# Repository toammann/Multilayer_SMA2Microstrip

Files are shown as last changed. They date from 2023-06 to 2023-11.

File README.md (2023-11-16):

# An Open-Source Multilayer SMA Coaxial to Microstrip Transition

Recently I came across [openEMS](https://www.openems.de/), a free and open electromagnetic field solver using the FDTD method.

The project has been around a few years, and it is quite impressive how far it has developed (05/2023). I was wondering if it is possible to solve a complex RF simulation task using open-source software only.

A license of a typical commercial RF simulation environment (CST, ADS, AWR...) can cost $1000/month easily. This price is out of range for hobbyists and small companies that do not use these software products on a daily basis.

I chose the task below as a representative test case:
> "Design a high performance SMA (SubMiniature version A) low cost Coaxial to Microstrip transition up to 20GHz on a FR4 multilayer stackup fabricated by an affordable PCB prototyping service."

Simulation tasks of this kind must be solved in the RF industry frequently because the transition needs to be designed for each specific layer stack with its own characteristic substrate materials, thicknesses and metal layers.

A list of open-source software used in this project:
- [OpenEMS](https://www.openems.de/)
- [FreeCAD](https://www.freecad.org/)
- [GNU Octave](https://octave.org/)
- [KiCAD](https://www.kicad.org/)
- [ParaView](https://www.paraview.org/)
- [QUCS](https://qucs.sourceforge.net/)
- [VS Code](https://code.visualstudio.com/)
- [Inkscape](https://inkscape.org/)
- [IEEE P370 Standard](https://opensource.ieee.org/elec-char/ieee-370)

## 1. Table of Contents

- [1. Table of Contents](#1-table-of-contents)
- [2. Rosenberger 32K242-40ML5 SMA Connector](#2-rosenberger-32k242-40ml5-sma-connector)
- [3. The Connector Model](#3-the-connector-model)
- [4. PCB Design Considerations and Manufacturing](#4-pcb-design-considerations-and-manufacturing)
- [5. Simulation Workflow](#5-simulation-workflow)
- [6. Simulation Results](#6-simulation-results)
- [7. Measurement Results](#7-measurement-results)
- [8. Conclusion](#8-conclusion)
- [9. KiCAD Howto](#9-kicad-howto)

## 2. Rosenberger 32K242-40ML5 SMA Connector
I have chosen a typical right-angle jack SMA connector. This connector type requires a cutout in the PCB edge, which is an additional design and manufacturing effort.

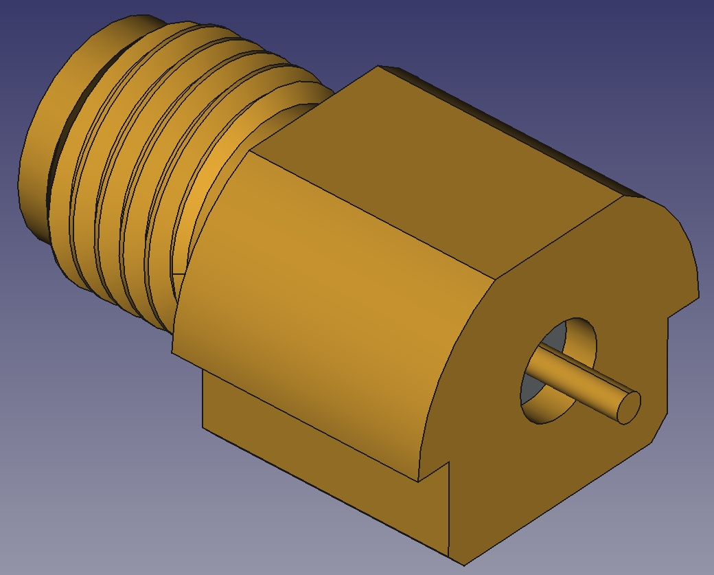
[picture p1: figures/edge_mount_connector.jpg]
fig_conn_wuerth

<p align = "center">Figure 1: A typical edge mount SMA connector to be mounted in a cutout.</p>

However, I like these connectors because the solder mount is very strong due to the large mounting area which results in very good mechanical durability. The parasitic inductance in the return current is also low because the solder joint is right at the circular edge of the coaxial outer conductor.

 Connectors of this kind are available from multiple manufacturers (Molex, Würth, Rosenberger...). I went with the Rosenberger one due to its availability where I live. Specifically, the 32K242-40ML5 made the run. It was about 6€ at rs-online.com. Figure 1 shows an exemplary CAD model of the Würth 60312202114307 (Rosenberger does not provide CAD a model for their part).

## 3. The Connector Model
Typically, the first step in designing a coaxial to microstrip transition is to request a simulation or mechanical model from the connector vendor. 

Today, most vendors provide detailed models for commercial simulators. However, in most cases an NDA (Non-Disclosure Agreement) is required. Sometimes the internals of the connector are even encrypted and therefore not visible to the user (e.g. SV Microwave).

I had no hope that Rosenberger would send a model to me - a private person without an NDA. I tried it nevertheless - with no success. They did not even bother to respond to my email.

So, in order to proceed the connector was cut in half with a rotary tool. The goal was to create a "poor man´s microsection view". I was quite surprised how well this tuned out. The result is good enough to take some measurements.

Ready to create a 3D model in FreeCAD!

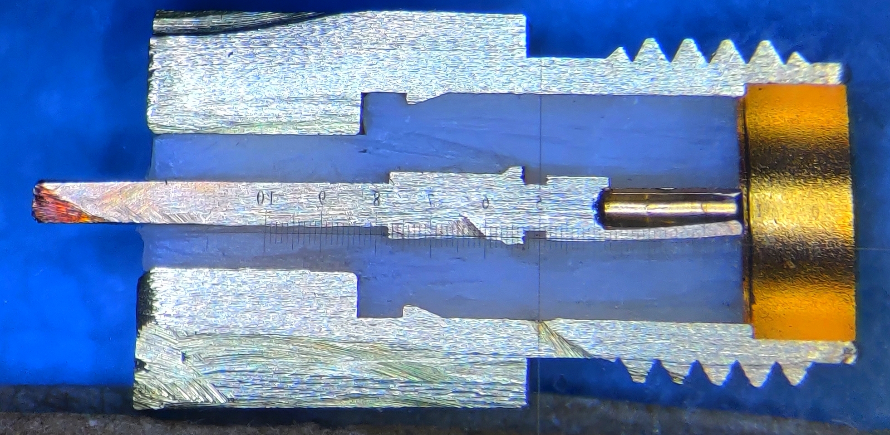
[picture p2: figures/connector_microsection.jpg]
fig_microsection

<p align = "center">Figure 2: Microsection view of the Rosenberger 32K242-40ML5</p>

To estimate the substrate permittivity, we can use the measured dimensions and the standard equation for the impedance of a coaxial waveguide. We know that the impedance inside of the connector must match $Z_0$=50Ohm at inner conductor clamping area on the right side of Figure 2. 

$$
    Z_0 = \frac{1}{2\pi}\sqrt{\frac{\mu_0\mu_r}{\epsilon_0\epsilon_r}}\ln\left(\frac{D}{d}\right)
$$

The relative permittivity of the connector substrate is found to be around $\epsilon_r$=2.08 for measured diameter values of D=4mm (outer), d=1.2mm (inner) and $\mu_r$=1,  $Z_0$=50Ohm. This is a typical value for a Teflon material.

## 4. PCB Design Considerations and Manufacturing
For a project of this kind choosing the right PCB (Printed Circuit Board) stackup and technology is actually more important than the choice of the SMA connector.

To prevent radiation effects at the interconnect, to minimize GND return current inductance and also for mechanical durability reasons it is usually beneficial to have an edge metallization in the area around the connector. However, this technology typically involves an additional PCB fabrication step which increases the cost significantly (which is especially true for common PCB prototyping platforms). Because this is a hobby project, I wanted it to be as cheap as possible.

In the past I have worked with a German PCB prototyping service [AISLER](https://aisler.net/?lang=en). I was quite satisfied with the quality of the delivered boards. Starting from 12/2022 AISLER has released a new FR4 6-layer PCB stackup that should work well for RF projects for various reasons. One very nice feature of AISLER is that "Castellated Holes" are free.

I had the idea to abuse this castellated hole feature to create a short piece of edge metallization. Placing the castellated holes and slots and also planning the board outline carefully was tricky. I even had to contact the support team of AISLER. The provided support was excellent!

The fabricated result is amazing! The edge metallization looks very, and it comes for free :)

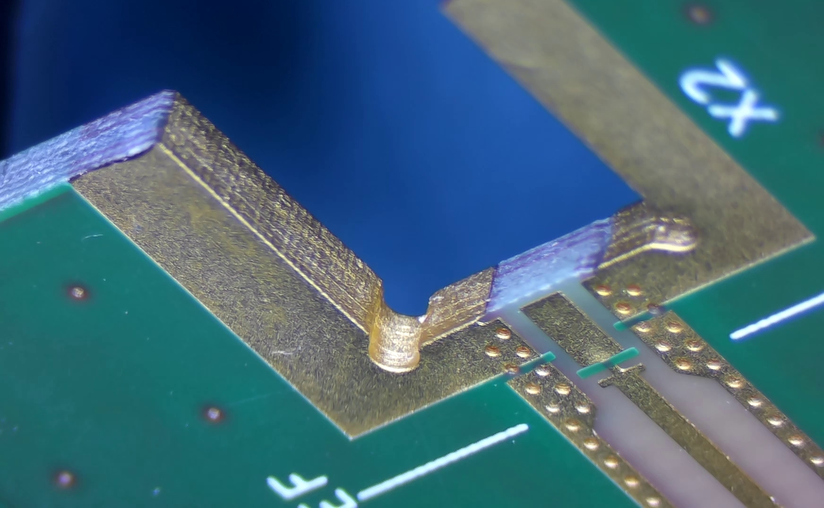
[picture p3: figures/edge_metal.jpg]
fig_edge_metal

<p align = "center">Figure 3: Edge-Metallization of the test board fabricated by AISLER using castellated slots.</p>

## 5. Simulation Workflow

There are two ways in openEMS to create the model required for the simulation. One can either use the octave/python interface to create the shapes that form the model directly in openEMS or to import *.stl mesh files.

I chose to create the entire model in FreeCAD. This has the benefit that all the import/export functions of FreeCAD can be used. One downside is that one might run into some [meshing issues](https://github.com/thliebig/openEMS-Project/discussions/43) if the mesh lines do not exactly hit the imported shapes (floating point accuracy).

The following figure shows the simulation workflow I came up with:

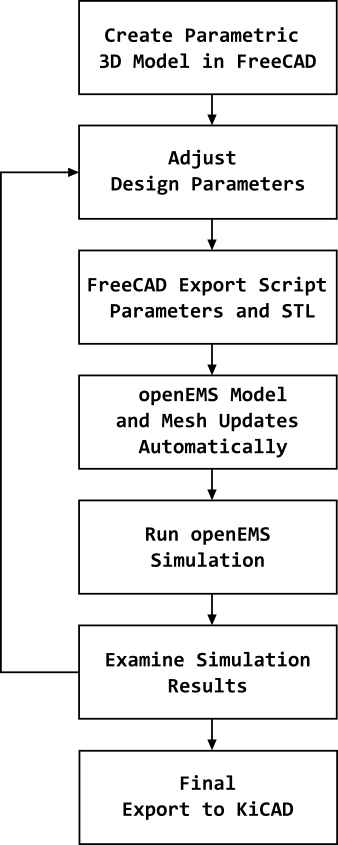
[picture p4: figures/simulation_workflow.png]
fig_simulation_workflow

<p align = "center">Figure 4: FreeCAD and openEMS Simulation Workflow</p>

This approach is quite powerful. The model dimensions are stored in one place only. So, when a dimension is changed in FreeCAD everything updates automatically. From the 3D model all the way to the mesh lines what enables quick and easy tuning of the model. In this way the workflow is almost similar to CST Microwave Studio, a commercial EM-Solver Suite.

Figure 5 shows the connector and PCB model in FreeCAD with a cut plane at y=0. The spreadsheet on the right side shows the parameter list where all dimensions of the model can be adjusted. The PCB core and prepreg materials are hidden.

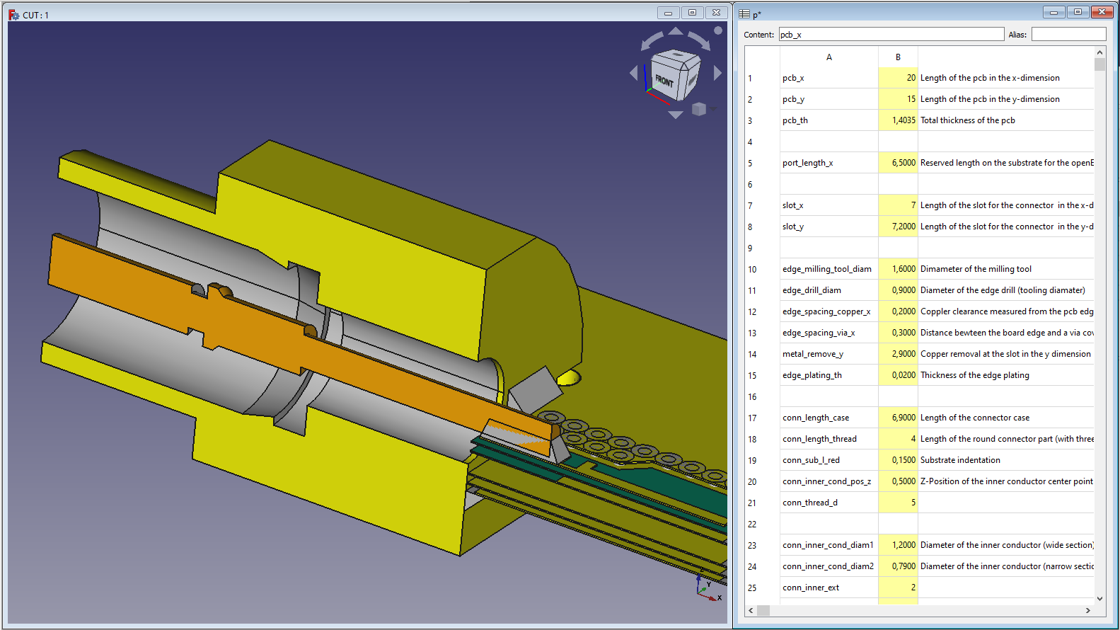
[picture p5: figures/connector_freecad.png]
fig_connector_freecad

<p align = "center">Figure 5: The Connector and PCB Model in FreeCAD</p>

Once the model parameters are settled in FreeCAD the user executes the Python FreeCAD export script which generates a set of *.stl files. These files are then imported by the octave openEMS script. Figure 6 shows the model and mesh result in AppCSXCAD the 3D Model editor/viewer of openEMS. 

Proper meshing techniques were applied in order to get a reasonably fast simulation and high accuracy results. One can clearly see how the mesh is denser in the area where the geometry details have a greater impact and less dense in less important areas.

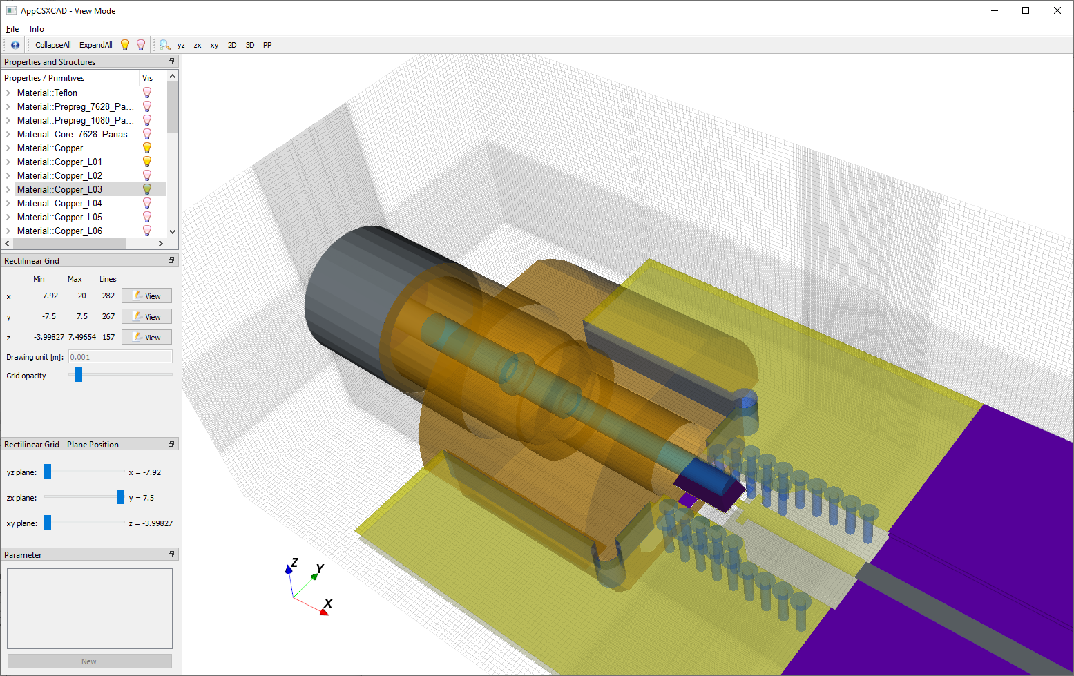
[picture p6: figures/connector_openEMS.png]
fig_connector_openems

<p align = "center">Figure 6: The Connector and PCB Model in AppCSXCAD (openEMS)</p>

The final output of the project - which is hopefully of use for the community - is a multilayer KiCAD footprint for the connector. Officially the KiCAD footprint editor does not support shapes on the internal metal layers. However, the footprint file can be modified with a text editor. Here shapes can be placed on the internal layers what works just fine. 

In order to use the KiCAD connector Footprint simply assign it to a symbol in the schematic and place "Copper Zones" (see example board) on the internal layers of your application board. Make sure to follow the  [bridges and frames](https://community.aisler.net/t/bridges-and-frames/49) design rules from AISLER. Everything else is handled in the KiCAD footprint.

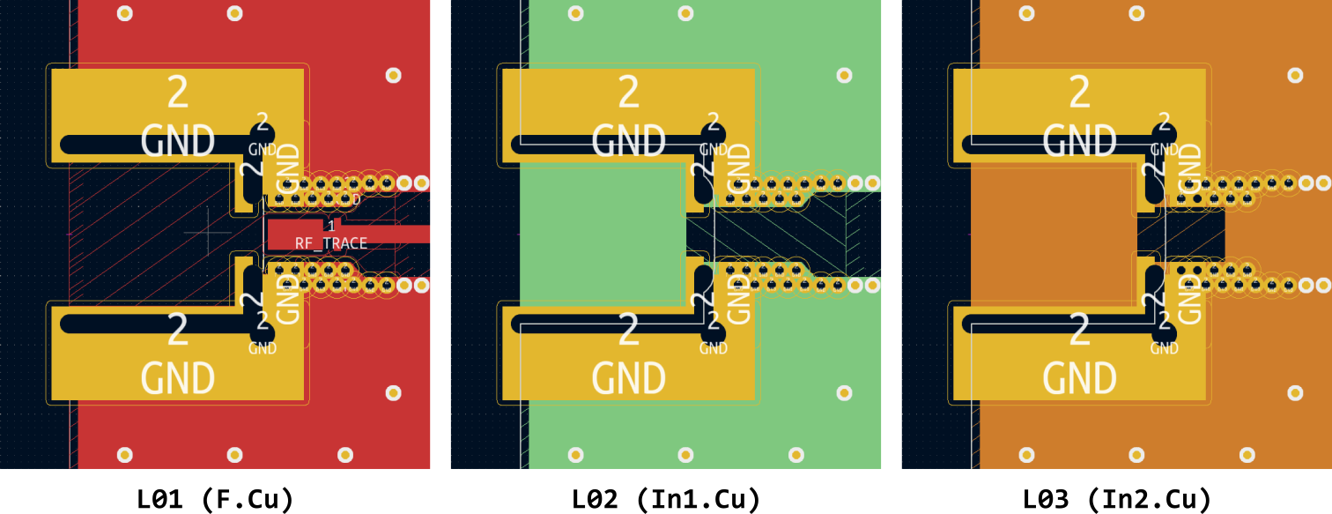
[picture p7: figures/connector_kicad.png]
fig_connector_kicad

<p align = "center">Figure 7: Multi-layer Connector Footprint in KiCAD.</p>

Finally, to test and measure the connector transition a 6-layer back-to-back test board was created in KiCAD. A total of three boards were manufactured by AISLER for around 20€. 

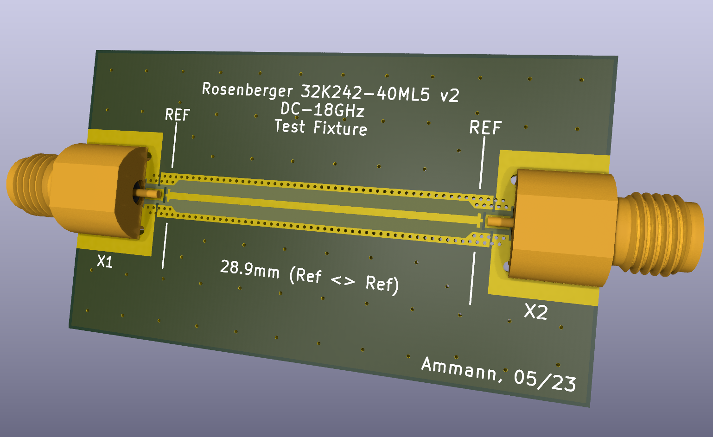
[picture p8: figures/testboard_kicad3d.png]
fig_tesetboard_kicad

<p align = "center">Figure 8: Test Fixture of the Rosenberger 32K242-40ML5 SMA Connector on  the AISLER 6LayerHD Stackup in KiCAD.</p>

After the fabrication of the PCB the SMA connectors were hand soldered on the test board as shown in Figure 9. 

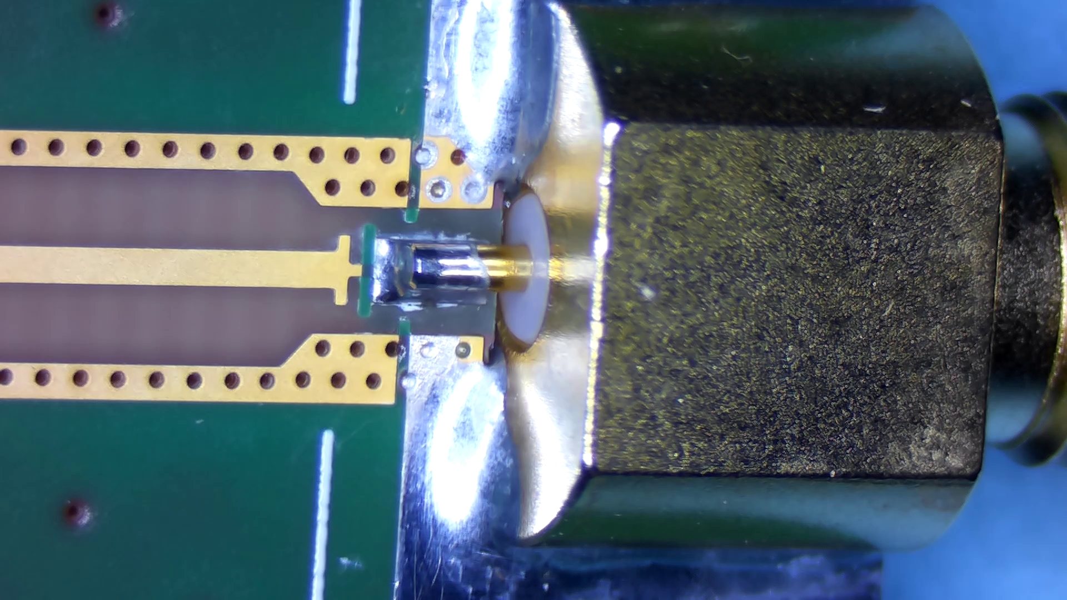
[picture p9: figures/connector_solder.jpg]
fig_connector_solder

<p align = "center">Figure 9: Rosenberger Connector Solder joint.</p>

## 6. Simulation Results

OpenEMS writes field data in a format suitable for ParaView. ParaView is an open software to visualize vector fields. Figure 9 shows an E-Field plot at the xz (y=0) plane (20GHz). One can clearly spot the transitions from the coaxial mode (vertical field vectors) to the microstrip mode. Also, the removal of the GND plane right under the connector Pad is noticeable. 

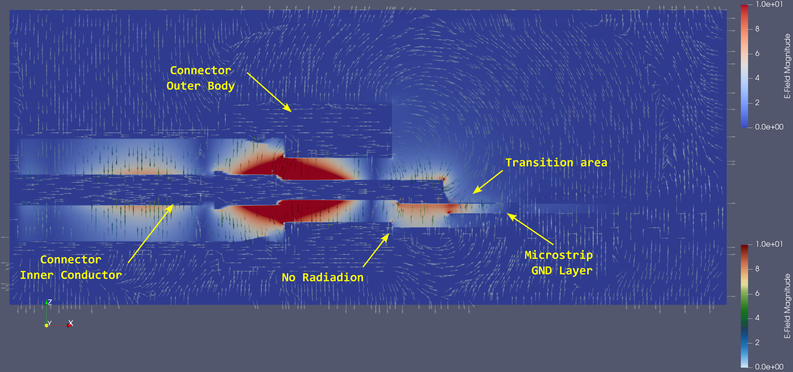
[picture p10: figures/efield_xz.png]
fig_efield

<p align = "center">Figure 10: Test Fixture of the Rosenberger 32K242-40ML5 SMA Connector on  the AISLER 6LayerHD Stackup.</p>

Above the right end of the inner conductor there is some small radiation visible. The field lines bend from the solder joint up to the top of the connector outer body. This undesired effect is given by the connectors construction and cannot be avoided.

At the edge where the connector and the PCB meet the internal copper layers of the PCB and the connector outer body form a parasitic parallel plate waveguide along the z dimension. It is important to avoid the excitation of this waveguide to prevent excessive leakage at higher frequencies. The field results clearly show that there is no radiation at the connector to PCB interface.

Finally let's examine the Scattering Parameters of the simulation. Figure 11 shows the simulation results calculated by openEMS. The reference plane for all S-Parameter results is located at the right edge of the capacitive compensation structure as shown in Figure 8. The exact location can be verified in the KiCAD PCB file. This edge is the transition where the connector footprint ends and the 50Ohm microstrip line starts. 

Port 1 is the coaxial one, Port 2 the microstrip port. A return loss greater than 23dB was achieved from DC to 20GHz.

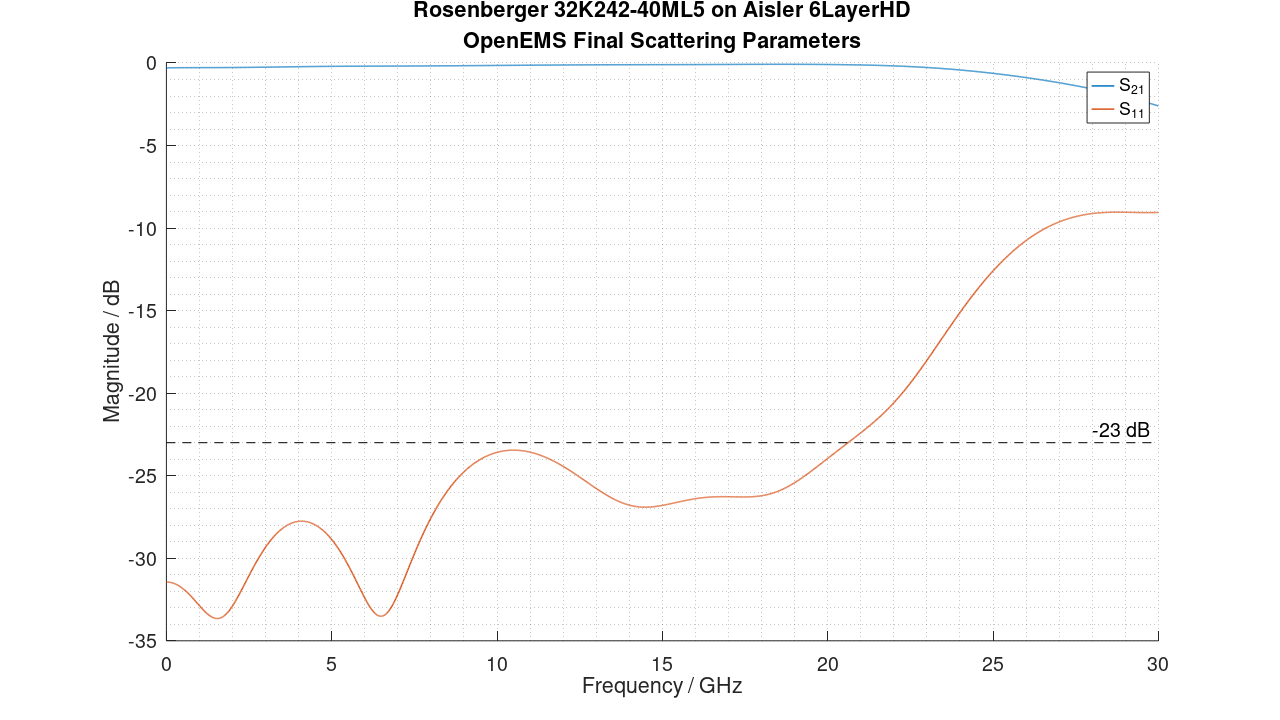
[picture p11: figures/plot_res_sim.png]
fig_plot_res_sim

<p align = "center">Figure 11: OpenEMS simulation result after optimization. Port 1 (coaxial), Port 2 (microstrip), Return Loss > 23dB.</p>

The smit chart plot in Figure 12 shows the in- and output trajectories on the complex reflection coefficient plane. They are nicely point symmetric to the origin. Overall, these results look promising. There is some margin for manufacturing tolerances left.

The openEMS simulation takes about 20 minutes to complete.

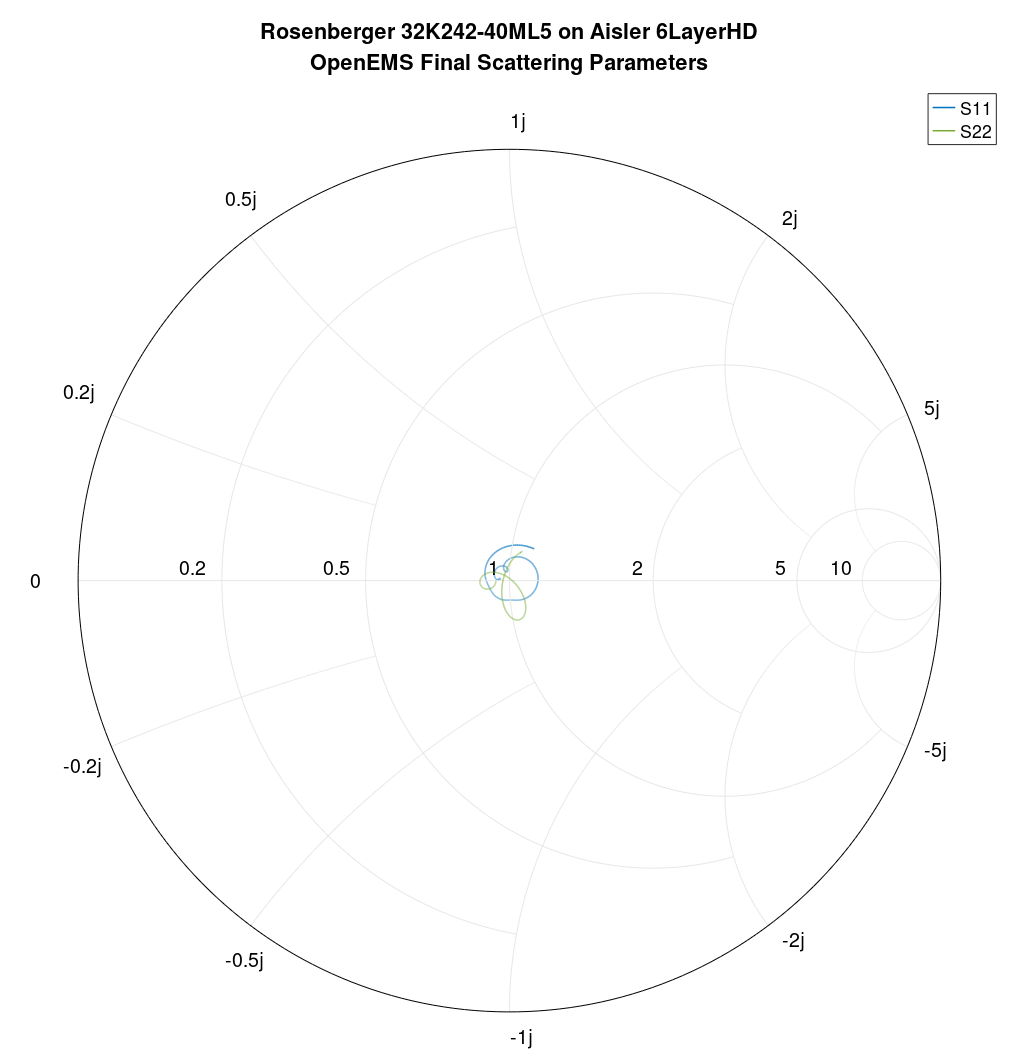
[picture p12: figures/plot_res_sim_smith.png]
fig_plot_res_sim_smith

<p align = "center">Figure 12: OpenEMS simulation result. In/ Output Matching from DC to 20GHz, Port 1 (coaxial), Port 2 (microstrip).</p>

## 7. Measurement Results

The fabricated test board from Figure 8 with two connectors back-to-back was measured with a high performance VNA (Vector Network Analyzer). The results are shown in Figure 13.

<p align = "center"><img src="./figures/plot_res_meas_testboard.png" alt="fig_plot_res_meas_testboard  width="800"></p>
<p align = "center">Figure 13: S-Parameter results, Test board Figure 8, two connectors back-to-back, reference plane at the SMA coax.</p>

Let´s take a closer look at this plot. The S21 curve is almost perfect. It is flat with no dips. However, one will notice that the magnitude return loss curves are not identical. So, the structure is not entirely symmetrical. This is due to manufacturing tolerances. Keep in mind that we are talking about a low-cost connector and PCB. The connectors are hand soldered, so some small displacements are expected.

In order to relate this result of Figure 13 to the simulated one in Figure 11 some approximate observations can be done. Approximately, we can think about the measured structure as two identical imperfectly matched two ports (the connector) with low insertion loss and an ideal transmission line in between. Because the insertion loss of the two ports is low, every miss match on either side will propagate directly through to the other side. The transmission line will further rotate the phase of the reflection coefficients with frequency. The 28.9mm transmission line is multiple wavelengths long at the highest frequency of interest (20GHz). So, it is safe to assume that all possible phase angles between the two imperfectly matched connectors will occur over frequency.

This phase related worst case impedance miss match $\Gamma_{max}$ may occur when two imperfectly matched ports with $|\Gamma_a|$ and $|\Gamma_b|$ are connected can be estimated from the following equation. It can be easily derived from the definition if the reflection coefficient:

$$
    |\Gamma_{max}| = \frac{|\Gamma_a| + |\Gamma_b|}{|\Gamma_a \Gamma_b| + 1}
$$

For this idealized analysis let´s assume identical connectors with $|\Gamma_a|=|\Gamma_b|=|\Gamma|$. From Figure 13 we take $|\Gamma_{max}|$=-15.67dB. Solving the above equation for $|\Gamma|$ gives us an estimation of the connector two-port return loss of:

$$
    |\Gamma| = \frac{1- \sqrt{1-|\Gamma_{max}|^2}}{|\Gamma_{max}|}= -21.63\mathrm{dB}
$$

So, we know simply by looking at Figure 13 closely that the achieved measured return loss of the connector is slightly worse than in the simulation.

To properly compare the simulation with the measurement results some advanced mathematical postprocessing must be applied to the data of Figure 13. There are two options: 

1. Perform a S-Parameter simulation using the touchstone files of the EM-simulation to model the back-to-back structure from Figure 8. In the simulator place the touchstone files back-to-back with a transmission line of the correct length in between. 
2. Cut the structure mathematically in half to separate the left from the right connector. De-embed the remaining transmission line in a second step.

Method 1. has the benefit of being easy to generate using any standard S-Parameter simulator such as Qucs. The downside of this method is that the single connector characteristics (left or right) are not extracted. However, the single connector characteristics are the one of interest when using the connector in an actual circuit. 

The approach in Method 2 extracts these single connector characteristics. This data can be compared directly to the simulation result which is desirable. However, the output data of this method is more difficult to generate.
The IEEE P370 Standard [(Electrical Characterization of Printed Circuit Board and Related Interconnects at Frequencies up to 50 GHz) ](https://ieeexplore.ieee.org/document/8078138) comes with an open source mathematical algorithm to achieve this goal. The source code can be found on the [IEEE GitLab](https://opensource.ieee.org/elec-char/ieee-370). Internally, it uses a time domain transformation approach.

Finally Figure 14 shows the prost processed measurement results from Figure 13 by applying Method 2 on the measured data.

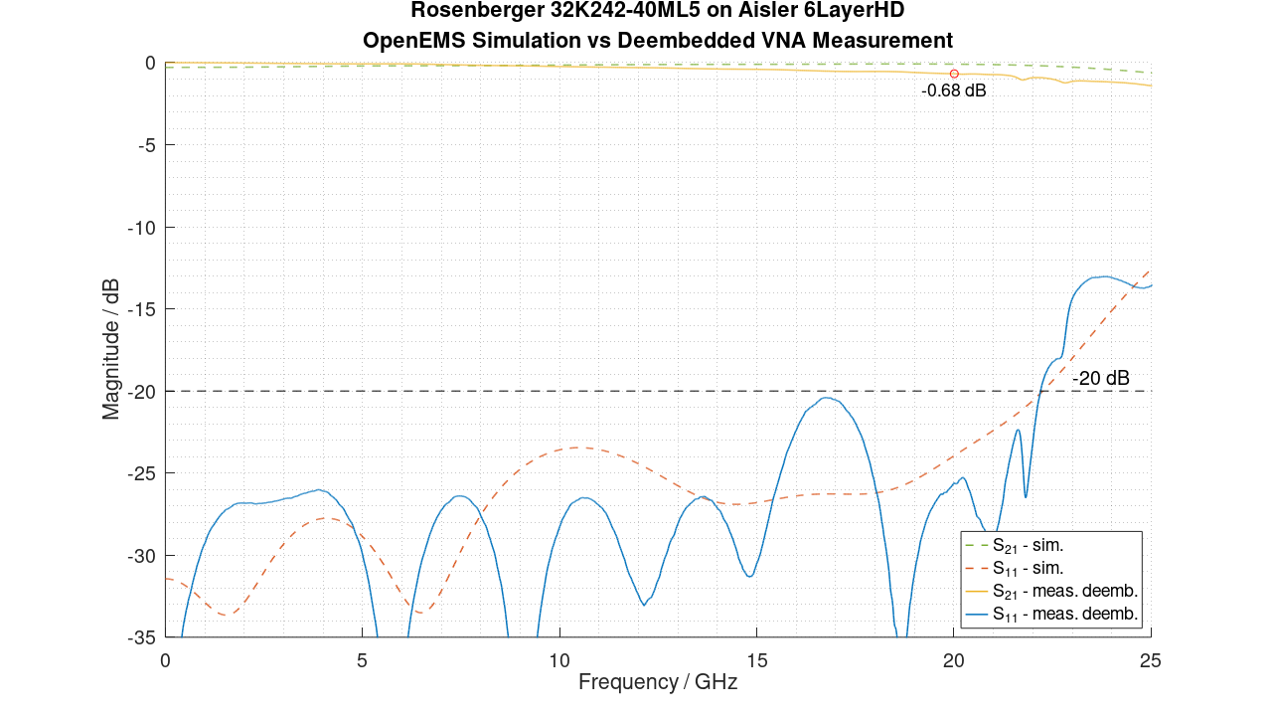
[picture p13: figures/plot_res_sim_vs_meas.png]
fig_plot_res_sim_vs_meas

<p align = "center">Figure 14: OpenEMS Simulated S-Parameters vs. VNA-Measurement (Post-Processed/De-Embedded via Method 2).</p>

We can see that the worst-case insertion loss around 17.5GHz is very close to our estimated value of -21.63dB which was calculated above. Overall, the agreement is impressive considering the large manufacturing tolerances of a PCB fabricated by a prototyping service and a hand soldered connector.

The connector itself has a very large return loss tolerance specification. From the datasheet:
> VSWR = 1.1 + 0.02 x 20GHz = 1.5 (RL = 14dB)

This is much worse than the measured result on its own! So, overall, the agreement is remarkable.

## 8. Conclusion

To test the openEMS FDTD-Solver a SMA coaxial to microstrip transition was designed and simulated. 

The Rosenberger 32K242-40ML5 connector has been integrated on a 6-layer test board with FR4 substrate fabricated by AISLER a German PCB prototyping service. Using castellated holes in a suitable configuration a PCB edge metallization has been realized with no additional cost. Finally, an easy-to-use KiCAD footprint was created. The footprint enables the user to design complex RF circuits up to 20GHz on the AISER 6LayerHD FR4 stackup.  

The transition is very low-cost and intended for hobbyist and prototyping use. A 20GHz SMA transition for under 20€ as a "one off prototype order" is to my knowledge unique. 

<div align="center">

| Item | Cost |
|:---|:---|
| 6-Layer PCB by AISLER (one piece)  | 20€/3 = 6.67€ |
| Rosenberger connector (two pieces) | 2*6€ = 12€ |
| Total Cost | 18.67€ |

 </div>

This case study shows that it is possible to design high performance RF hardware using open-source software only.

The agreement between simulated and measured results is very good especially considering the high manufacturing tolerances due to hand soldering and a low-cost PCB. OpenEMS does a remarkable job here! In my opinion this simulator gets way too little attention for its capabilities.

Unfortunately, openEMS lacks detailed training materials what makes the software hard to use for a beginner. This case study demonstrates how powerful this free software actually is. Hopefully, it will encourage other people to publish simulated and measured results. This will greatly improve the confidence in the simulator and hopefully attract more users. 

The more users the more information is available in the form of tutorials or forum discussions.

## 9. KiCAD Howto
Please find instructons how to use the KiCAD footprint [here](./KiCAD_Rosenberger_32K242-40ML5_Footprint/Rosenberger_32K242-40ML5_Footprint_HowTo.md).

 ### License Information

- Layouts, 3D models, footprints: Creative Commons Legal Code CC0 1.0 Universal
- Program code: BSD 2-Clause License

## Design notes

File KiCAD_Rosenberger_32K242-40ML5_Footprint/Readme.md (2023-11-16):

# How to Use the Rosenberger32K242-40ML5 KiCAD Footprint

## Version History
 - 15.11.2023 - Update milling contours to support the AISLER 1.8mm outline tool diameter update.  
 - 16.08.2023 - Updated RF structure
 - 05.05.2023 - Initial: Rosenberger_32K242-40ML5v1.kicad_mod

## Current Status
 - Unferified (changes were made to the design but there was no fabrication run)
## Requirements
- Tested with KiCAD 7.0
- Compatible with the  [AISLER 6LayerHD](https://community.aisler.net/t/6-layer-hd-pcb-stackup/1703)
 stakup only. NO other layer stack will work

## Installation Instructions

1. Save the footprint folder to a location of your choice
2. Add the "RF_Connectors.pretty" folder to your KiCAD footprint library (Footprint Editor -> Manage Footprint Libraries)
3. Make sure that the STEP file "Rosenberger_32K242-40ML5.step" is in the same folder as the *.kicad_mod file
4. Done

## How to use it on a PCB

1. Assign the footprint to a suitable schematic symbol of your choice
2. In the layout make sure to have the footprint covered by GND plane (Copper Zone) on every layer
3. Add custom design rule for the connector type to avoid DRC errors:

   ```
   PCB-Editor -> File -> Board Setup -> Design Rules -> Custom Rules
   ```

   ```
   (version 1)

   # Rule for the Rosenberger_32K242-40ML5v2 footprint
   # All pads of the footprints are a member of the 'pad_Rosenberger_32K242-40ML5v2'
   # Group. Note that some of these pads are on the innner layer. The group membership
   # of these pads must be managed using a text editor
   # (currently not supported by the KiCAD footprint editor)

   (rule "Rosenberger_32K242-40ML5v2 ignore annular_width"
      (condition "A.memberOf('pad_Rosenberger_32K242-40ML5v2')")
      (constraint annular_width (min -999mm))
   )

   # Rule for the Rosenberger_32K242-40ML5v2 footprint
   (rule "Rosenberger_32K242-40ML5v2 ignore edge_clearance"
      (condition "A.memberOf('pad_Rosenberger_32K242-40ML5v2')")
      (constraint edge_clearance (min -999mm))
   )
   `````

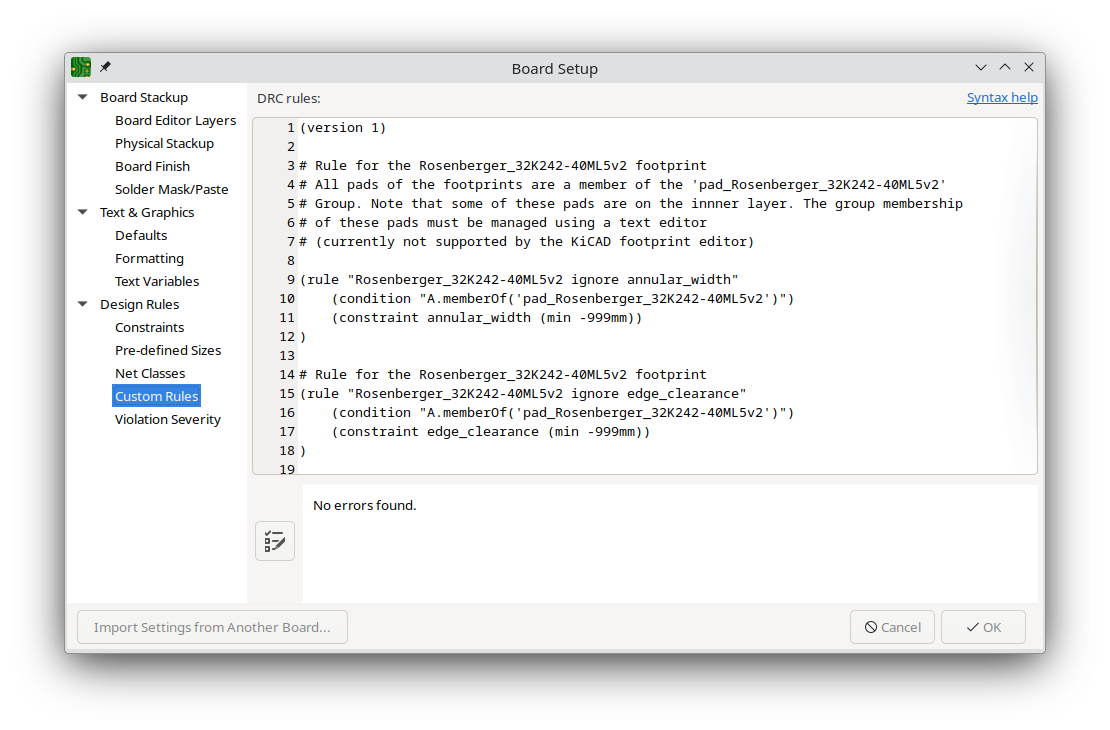
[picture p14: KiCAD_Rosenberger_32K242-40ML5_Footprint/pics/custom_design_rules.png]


4. The footprint makes use of castelleted holes/slots to create a short piece of edge plating. Therefore the [AISLER design rules](https://community.aisler.net/t/castellated-holes/48) for castellated holes apply. This means that you have to define [custom bridges and frames](https://community.aisler.net/t/custom-bridges-and-frames/49).

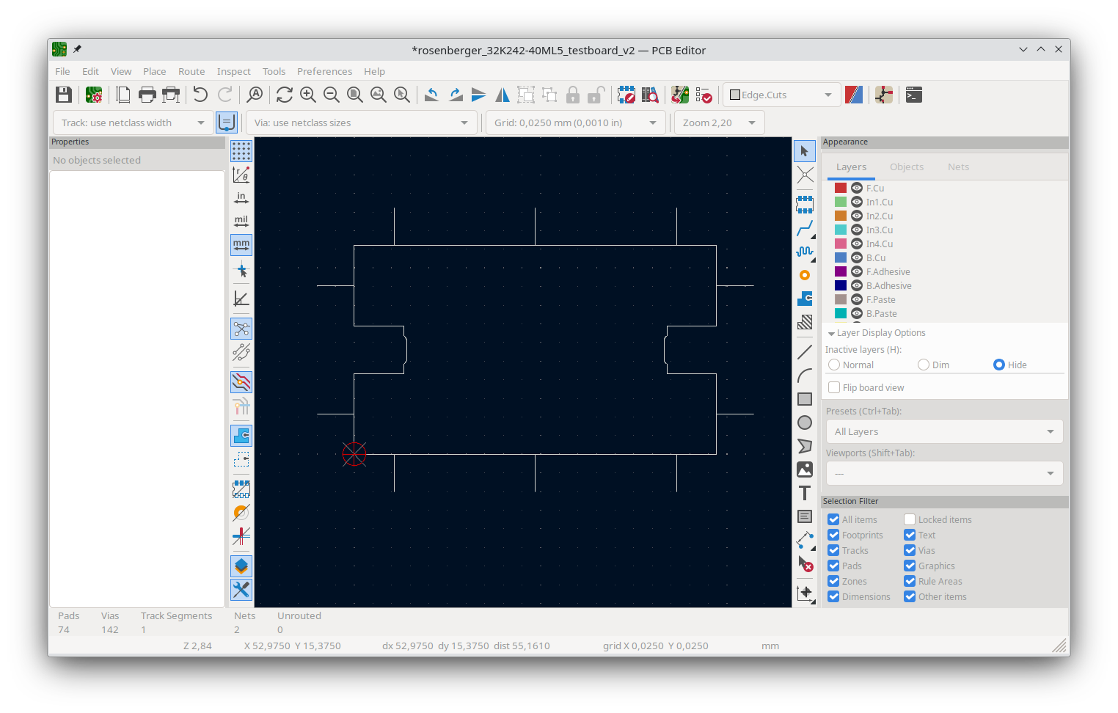
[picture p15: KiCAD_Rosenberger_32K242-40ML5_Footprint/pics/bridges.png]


## Order the board

There will be some warings when ordering the board at AISLER. This is to be expected due to the careful placement of the castellated slots to create an edge plating. 

The following warnings are normal:

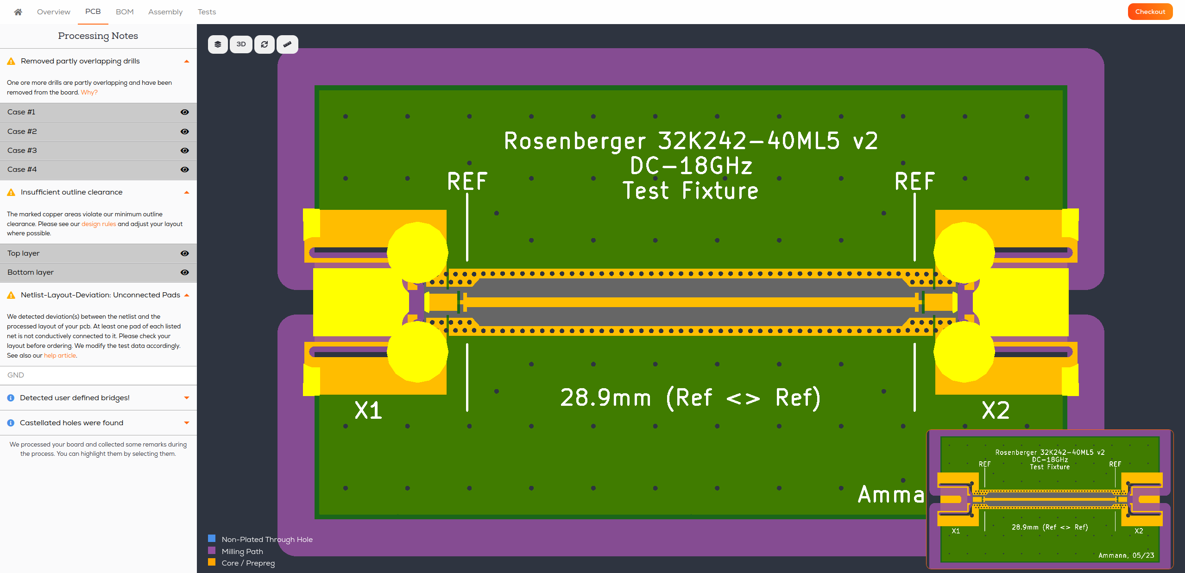
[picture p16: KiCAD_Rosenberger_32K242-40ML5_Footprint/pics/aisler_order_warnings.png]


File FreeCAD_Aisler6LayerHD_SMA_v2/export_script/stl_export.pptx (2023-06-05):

## STL Export: Angular Deflection

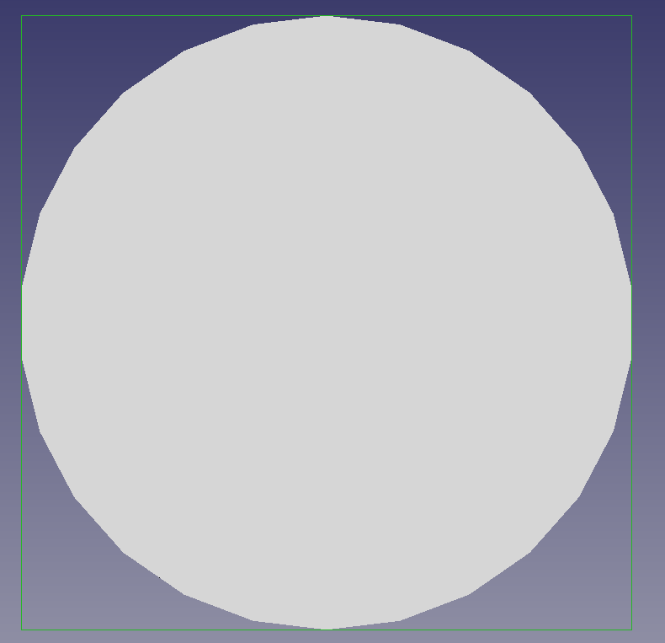
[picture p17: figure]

Method 1 (standard export)
Angular Deflection 28.5°

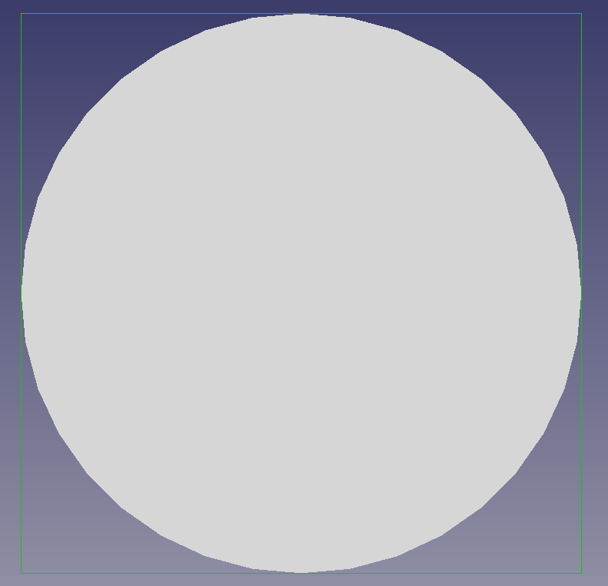
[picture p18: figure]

Method 2 (mesh export)
Angular Deflection 20°

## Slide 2

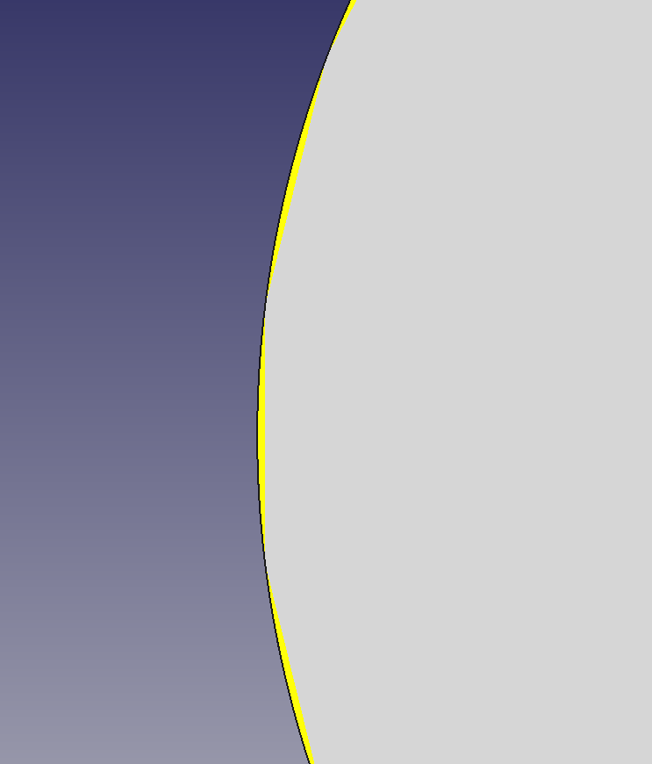
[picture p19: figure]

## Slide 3

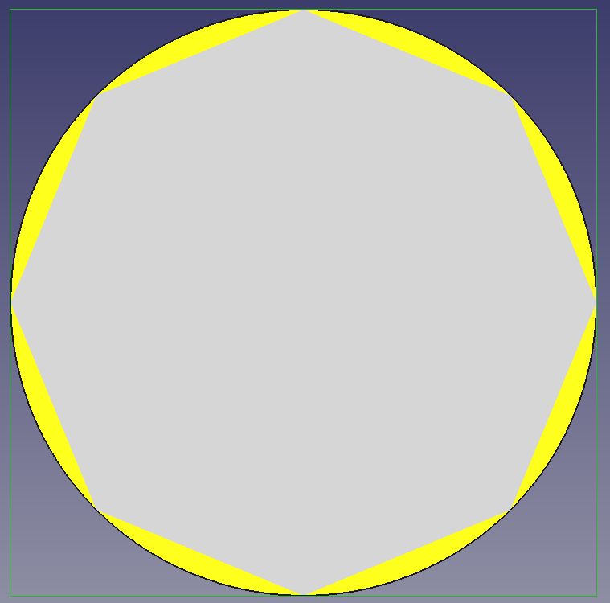
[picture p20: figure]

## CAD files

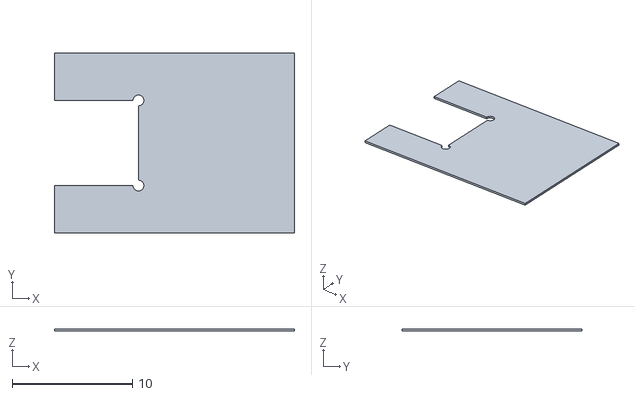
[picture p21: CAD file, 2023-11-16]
FreeCAD_Aisler6LayerHD_SMA_v2/sub04_core.stl
20.0 x 15.0 x 0.2

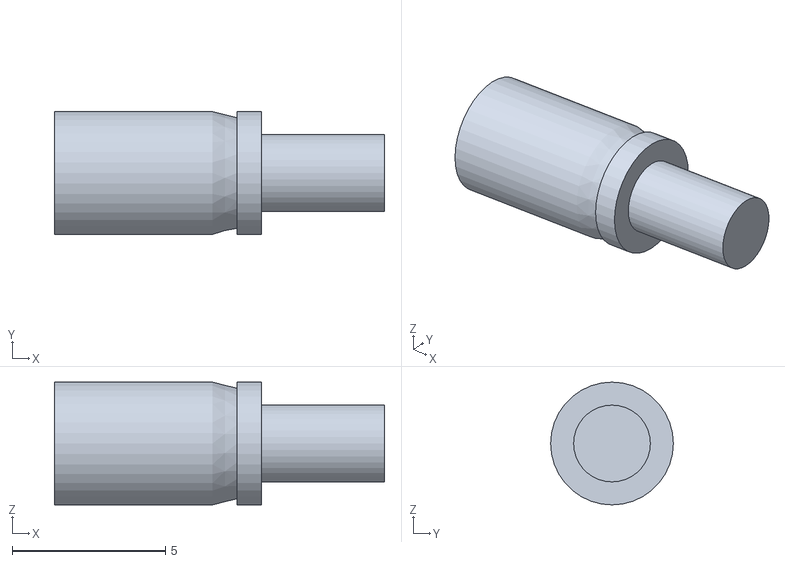
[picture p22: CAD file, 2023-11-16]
FreeCAD_Aisler6LayerHD_SMA_v2/conn_sub.stl
10.8 x 4.00 x 4.00

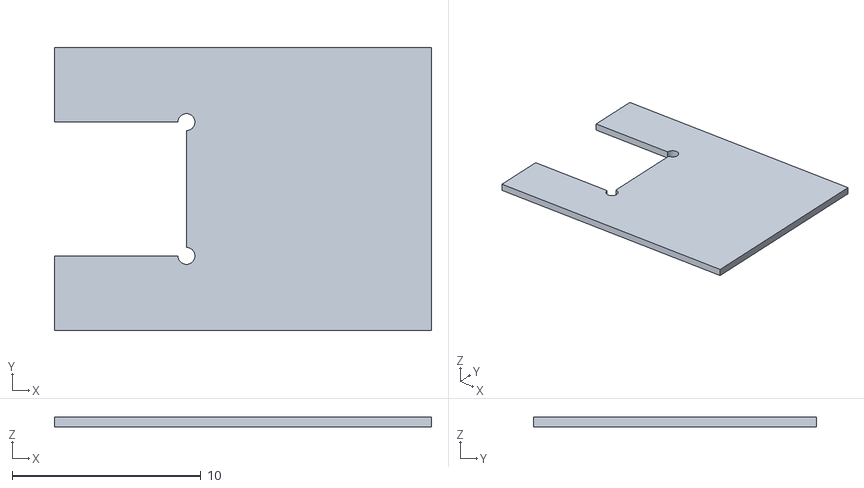
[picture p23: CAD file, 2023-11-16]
FreeCAD_Aisler6LayerHD_SMA_v2/sub03_prepreg.stl
20.0 x 15.0 x 0.511

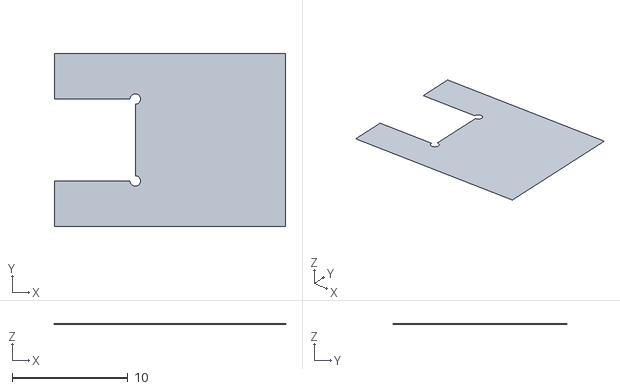
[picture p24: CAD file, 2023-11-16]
FreeCAD_Aisler6LayerHD_SMA_v2/l04_gnd.stl
20.0 x 15.0 x 0.035

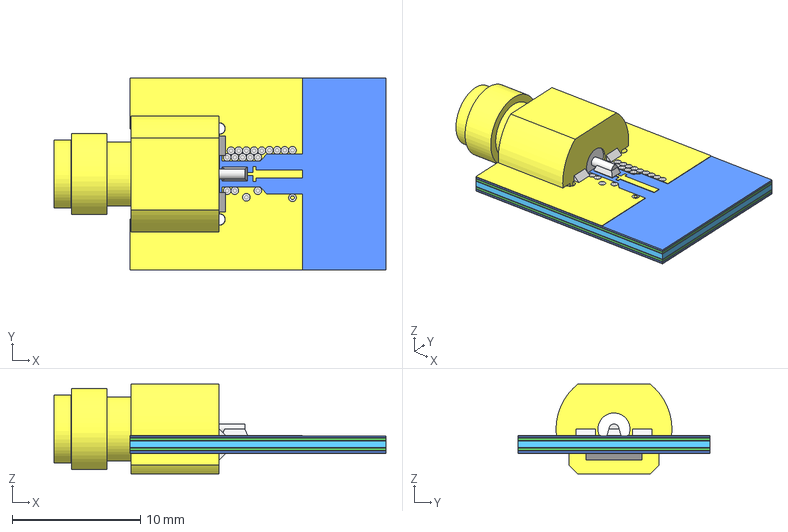
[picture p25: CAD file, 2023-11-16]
FreeCAD_Aisler6LayerHD_SMA_v2/Aisler6LayerHD_SMA_v2.FCStd
25.9 x 15.0 x 7.00 mm
l01_gnd_north
l01_gnd_south_mirror
l01_rf_trace
l02_gnd_north
l02_gnd_south_mirror
l02_neg
l03_gnd
l03_neg
l04_gnd
l05_gnd
l06_gnd
sub01_prepreg
sub02_core
sub03_prepreg
sub04_core
sub05_prepreg
edge_plating
edge_plating_mirror
conn_sub
conn_inner_cond
conn_outer_body
conn_thread
via0_1
via0_2
via0_3
via0_4
via0_5
via1_1
via1_2
via1_3
via1_4
via1_5
via0_1_mirror
via1_1_mirror
via1_2_mirror
via1_3_mirror
via1_4_mirror
via0_2_mirror
via0_3_mirror
via0_4_mirror
via0_5_mirror
via1_5_mirror
via2_1
via2_2
via2_3
via2_4
via2_1_mirror
via2_2_mirror
via2_3_mirror
via2_4_mirror
solder_top
solder_top_mirror
solder_top_pin
solder_bot

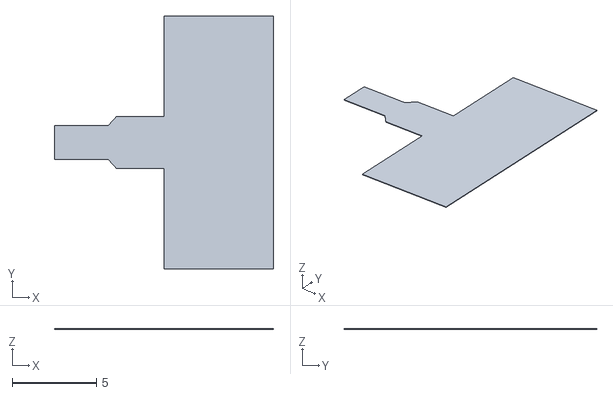
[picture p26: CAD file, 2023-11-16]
FreeCAD_Aisler6LayerHD_SMA_v2/l02_neg.stl
13.0 x 15.0 x 0.035

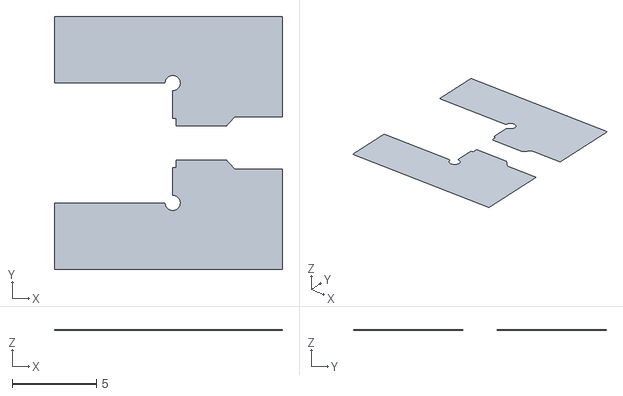
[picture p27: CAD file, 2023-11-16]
FreeCAD_Aisler6LayerHD_SMA_v2/l01_gnd.stl
13.5 x 15.0 x 0.04

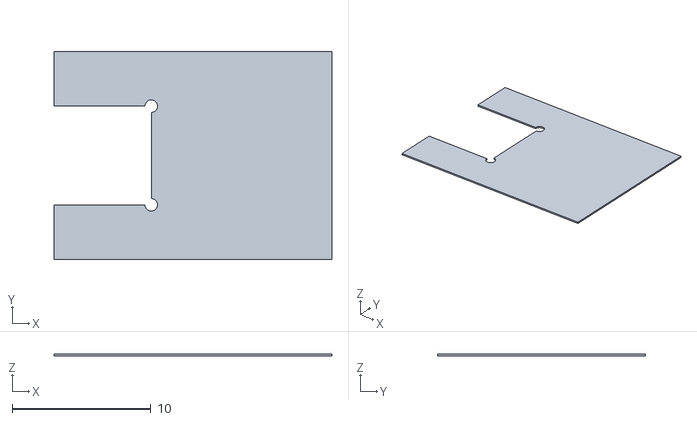
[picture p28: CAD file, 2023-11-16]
FreeCAD_Aisler6LayerHD_SMA_v2/sub01_prepreg.stl
20.0 x 15.0 x 0.136

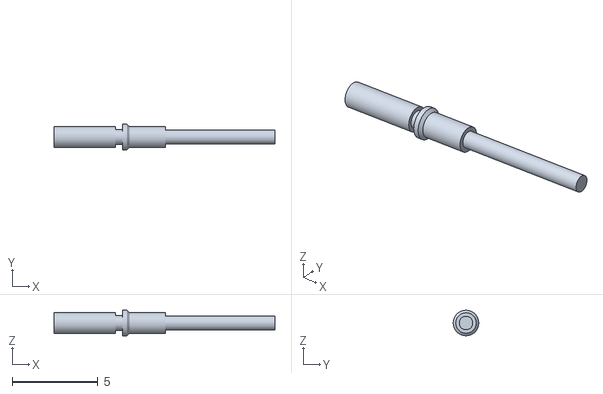
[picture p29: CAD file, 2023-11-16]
FreeCAD_Aisler6LayerHD_SMA_v2/conn_inner_cond.stl
12.9 x 1.50 x 1.50

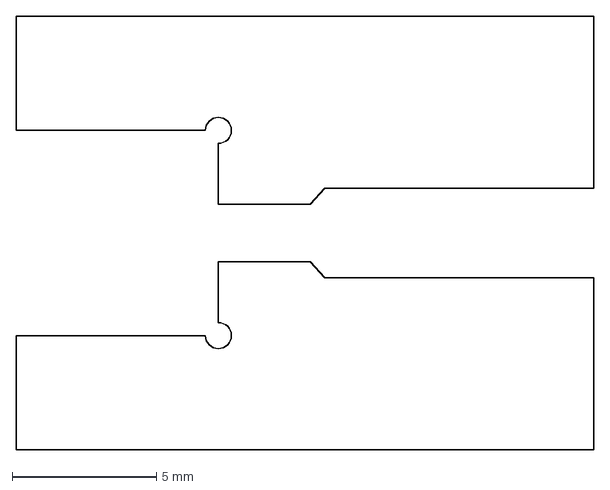
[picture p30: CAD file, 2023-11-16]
FreeCAD_Aisler6LayerHD_SMA_v2/Aisler6LayerHD_SMA_v2_L02.dxf
20.0 x 15.0 mm

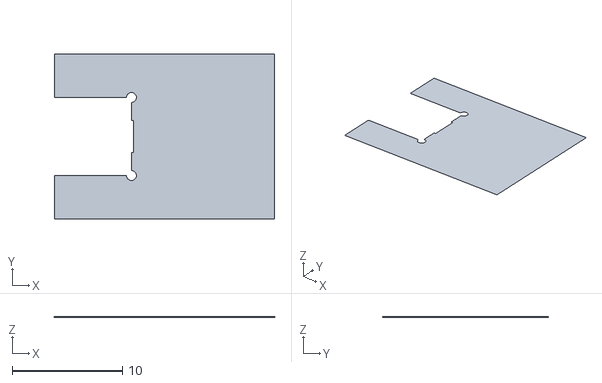
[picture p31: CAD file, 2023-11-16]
FreeCAD_Aisler6LayerHD_SMA_v2/l06_gnd.stl
20.0 x 15.0 x 0.04

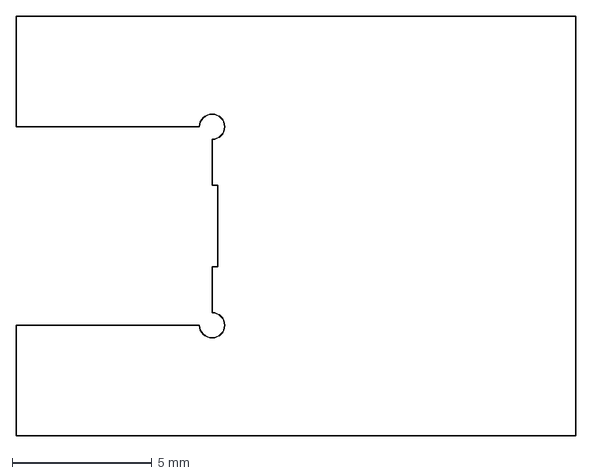
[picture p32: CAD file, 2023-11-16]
FreeCAD_Aisler6LayerHD_SMA_v2/Aisler6LayerHD_SMA_v2_L06.dxf
20.0 x 15.0 mm

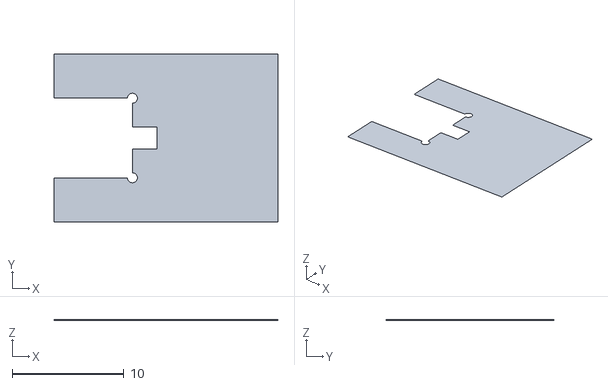
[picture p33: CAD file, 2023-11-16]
FreeCAD_Aisler6LayerHD_SMA_v2/l03_gnd.stl
20.0 x 15.0 x 0.035

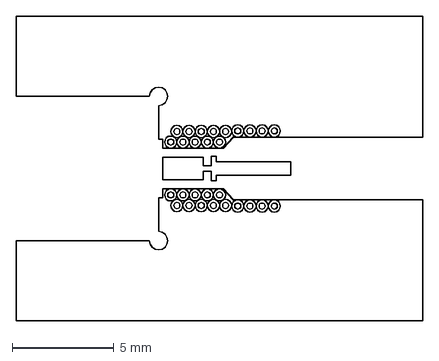
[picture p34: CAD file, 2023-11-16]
FreeCAD_Aisler6LayerHD_SMA_v2/Aisler6LayerHD_SMA_v2_L01.dxf
20.0 x 15.0 mm

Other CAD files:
FreeCAD_Aisler6LayerHD_SMA_v2/sub05_prepreg.stl
FreeCAD_Aisler6LayerHD_SMA_v2/conn_outer_body.stl
FreeCAD_Aisler6LayerHD_SMA_v2/l02_gnd.stl
FreeCAD_Aisler6LayerHD_SMA_v2/Aisler6LayerHD_SMA_v2_L04.dxf
FreeCAD_Aisler6LayerHD_SMA_v2/Aisler6LayerHD_SMA_v2_EdgePlating.dxf
FreeCAD_Aisler6LayerHD_SMA_v2/Aisler6LayerHD_SMA_v2_L03.dxf
FreeCAD_Aisler6LayerHD_SMA_v2/edge_plating.stl
FreeCAD_Aisler6LayerHD_SMA_v2/l01_rf_trace.stl
FreeCAD_Aisler6LayerHD_SMA_v2/l03_neg.stl
FreeCAD_Aisler6LayerHD_SMA_v2/l05_gnd.stl
FreeCAD_Aisler6LayerHD_SMA_v2/solder_bot.stl
FreeCAD_Aisler6LayerHD_SMA_v2/solder_top_pin.stl
FreeCAD_Aisler6LayerHD_SMA_v2/sub02_core.stl
FreeCAD_Aisler6LayerHD_SMA_v2/via_fence.stl
FreeCAD_Aisler6LayerHD_SMA_v2/via_trans.stl

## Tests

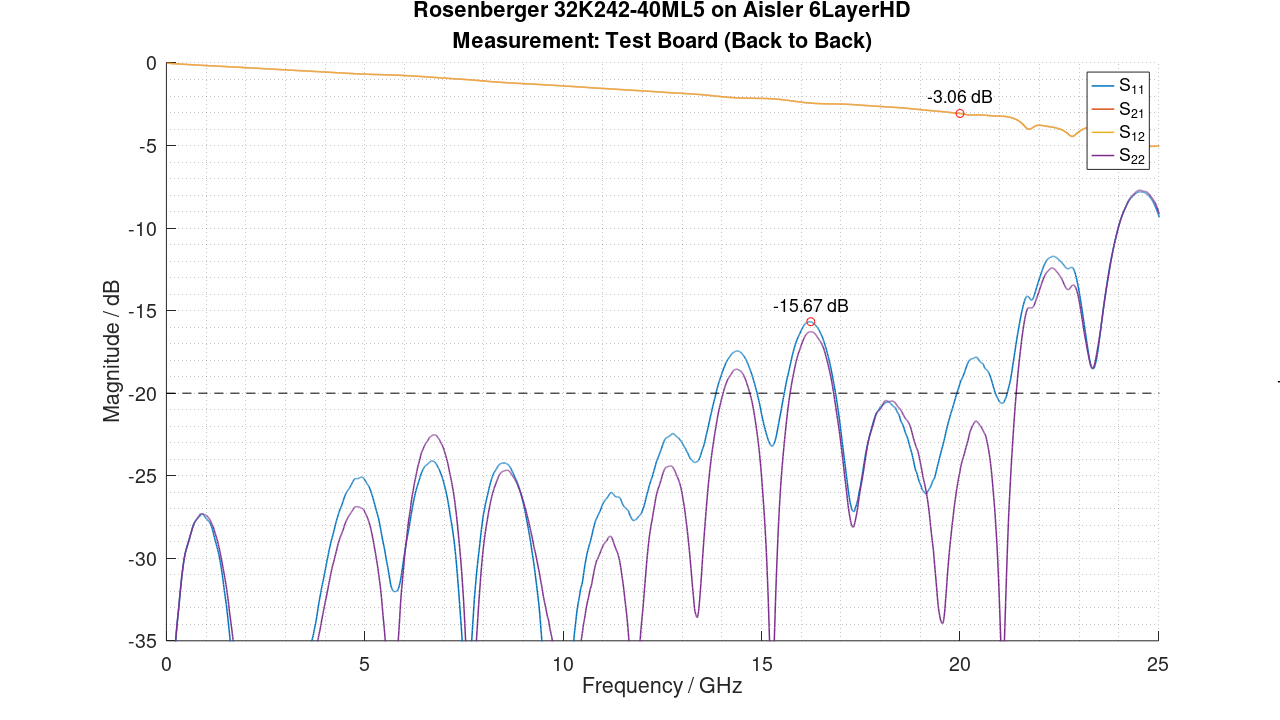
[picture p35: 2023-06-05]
figures/plot_res_meas_testboard.png

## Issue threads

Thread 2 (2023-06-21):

wrong directory name in aisler_sma_v2.m

PinkMushroom, 2023-06-21:
model_dir = [parentDir, filesep, '**FreeCAD**_Aisler6LayerHD_SMA_v2'];

the directory name should be

**FreeCad**_Aisler6LayerHD_SMA_v2'

toammann, 2023-06-23:
Hey,
I am not sure why this fails for you. The 'FreeCad_Aisler6LayerHD_SMA_v2' model directory is located one level above the working directory. This is the root repository folder (I called this parent directory).

The openEMS solver needs a full path to the *.stl file. I was unable to get it run by using relative paths.

So, this should be correct. Please note that the windows file seperator "\" must be escaped. So "\" gehts replaced by "\\". If you run this on linux this must be changed to the linux file seperators.

Regards

PinkMushroom, 2023-06-24:
The directory there, it's the directory name.
Git clone created a directory
using "Cad" instead of "CAD"

toammann, 2023-06-25:
Hey, thanks for pointing this out. Not sure why this happend. I have changed the directory name

Closed 2023-06-24.

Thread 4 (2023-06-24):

strange errors, possible path name issues ?

PinkMushroom, 2023-06-24:
First there was the problem with the case of the directory name being incorrect.

Now I am getting a large number of errors because the STL files cannot be found, and this is what i see for the path name

```
CSPrimPolyhedronReader::ReadFile: file invalid or empty, skipping ...
CSPrimPolyhedronReader::ReadFromXML: Failed to read file.
2023-06-24 13:38:00.446 (   0.002s) [        7BDF79C0]       vtkSTLReader.cxx:106    ERR| vtkSTLReader (0x564460111f80): File /home/<username>/src/OpenEMS/Multilayer_SMA2Microstrip/FreeCAD_Aisler6LayerHD_SMA_v2\solder_top_pin.stl not found

```

Notice that there is a backslash in the directory name. I noticed in the othe issue discussion you talk about your installation being "C:\openEMS", so I wonder if these might be windows/linux issues.

PinkMushroom, 2023-06-24:
oh good grief.
you addressed this in the other issue.

PinkMushroom, 2023-06-24:
you addressed this in the other issue.

Closed 2023-06-24.

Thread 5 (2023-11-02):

Rosenberger SMA Step model

oberstet, 2023-11-02:
first of all, thank you so much for doing this work, specifically also using OSS, and for publishing your work again as OSS!  awesome!

by coincidence, I'm using exactly this part and got exactly the problem you tackle (https://community.aisler.net/t/how-to-correct-this-complex-pcb-outline-with-cutouts/3270). well, I only need sub-ghz, but obviously I still need to fit the part physically.

anyways, just a detail, but I stumbled across "Rosenberger does not provide CAD a model for their part" in the project readme .. maybe just outdated, as they do in fact provide a Step model

https://products.rosenberger.com/radio-frequency/connectors/157634/32k242-40ml5-right-angle-jack-pcb

but they do _not_ provide an electronic footprint! unfortunately only old-school CAD drawing.

which is why every user will have to redo/repeat work. not ideal. why don't they provide complete models and publish to snapeda or ultralibrarian or whatever?

will you publish it there as well?

> caveat: I have no idea whether those sites allow that, legal stuff etc. I'm a PCB newbie that just failed to create a proper footprint for this part, but I wouldn't publish it anyways as I'm just not confident enough in this area - I'm mostly a software guy;)

oberstet, 2023-11-02:
here:

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

> note: seems I still haven't understood how/where kicad looks for footprints .. I tried the rosenberger step model within your existing design .. but well. anyways. that should be fixable.

toammann, 2023-11-03:
Hey oberstet,
Thanks for your comments!

>  maybe just outdated, as they do in fact provide a Step model

Thats a good find, I spent quite some time looking for a CAD model. I asked rosenberger via email to provide one. So, this model is definitly new. I will add it to footprint!.

> which is why every user will have to redo/repeat work. not ideal. why don't they provide complete models and publish to snapeda or ultralibrarian or whatever?

Unfortunenately, this is not possible for RF-Parts of this kind. The connector is rated up to 18GHz where the pad capacitance GND return current inductance and all these little parasitics have a big influence on the connector performance.

These parasitics will vary greatly with with diffrent substrate materials (varying permittivity). So, if you were to design a footprint for a stackup which uses e.g. the RO4350 (Er=3.5) RF laminate you are likely to use an EM simulator to optimize the pyscial dimensions of the pad structures and via placements and so on.

If you want to use the same footprint now on a FR4 susbstrate (Er=4.5) the permittivity is another one and therefore all the dimensions will be off slightly which will result in reduced performance at the higher frequencies.

Therefore, a footprint of aconnector is valid for ONE layer stack with defined substrate materials only. This is true for RF connectors in general.

If you want to use the RF connector only up to 1GHz or so it will not matter so much of course.

Regards,
Tobias

toammann, 2023-11-03:
Hey,
i noticed, that the board outline is not rendered correctly in your Board. This is due to the user defined bridges. Aisler requires them to be defined in the edge cuts layer witch results in this rendering issue. Just delete them and it should render correctly..

https://community.aisler.net/t/custom-bridges-and-frames/49

Regards

oberstet, 2023-11-03:
> Thats a good find, I spent quite some time looking for a CAD model. I asked rosenberger via email to provide one. So, this model is definitly new. I will add it to footprint!.

great, thanks a lot!

just one note: it might be good/safe to add some note next to the license file that even though your repo/material is CC0/MIT (awesome!), the Rosenberger STEP file is not. surprisingly (I just verified), to download that file, I didn't need to register or even sign anything, and I haven't found/seen a license file - the only thing that one is shown is a note about "we are not liable if things go south". which is fine for me;)

> Therefore, a footprint of aconnector is valid for ONE layer stack with defined substrate materials only. This is true for RF connectors in general.

ok, understood. I wasn't aware. I only have limited understanding of RF stuff, and pretty much zero experience;) thanks for explaining!

my hope is, for sub-ghz (430-880mhz), I can get sth done/working nevertheless. fwiw, I want to create a handheld Linux + RT cognitive radio with dual RF and both built-in planar helical antennas and external connectors. but actually, being a SW guy, I want to get back/up to bits as fast as possible;)

> i noticed, that the board outline is not rendered correctly ...

ahh, ok, I have to read up / dig into that. thanks!

> I think it is a good idea to write a short section on "How to use the footprint".

that would be fantastic!

also, ideally, a user (well, at least me) would like to just drop a symbol/footprint lib for the part into his/her project, and then just use it without fiddling with paths or what

or even better: add a tagged release of a GH repo to his/her git repo as a submodule

https://git-scm.com/book/en/v2/Git-Tools-Submodules

that way, I could just sync with upstream to easily follow updates.

not sure if there is an established best practice in the KiCad community how people share and sync parts across projects using Git ... source driven collaboration etc

toammann, 2023-11-16:
Hello,
I have releaed an update of the connector. I made changes but I did not order a board so far to test the changes. To get around the licensing issues I added my self drawn connector footprint from the FreeCAD 3D model.

Regards
Tobias

oberstet, 2023-11-16:
fantastic!! thanks a lot=)

I will test/use that soonish. currently I'm still figuring out my antenna in openEMS .. focusing on 446-930mhz skipping 223mhz- .. I've recognized now it is quite a challenge already fitting into the dimensions, and fully planar .. anyways ... I got coiled helical for those freqs working with quite good S11 ... but not in the dims and not planar ... atm fighting with dump and viewing 3d E-fields in paraview ..

Closed 2023-11-16.

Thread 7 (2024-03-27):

Aisler discontinued 6-layer PCB's, any suggestions?

KajWiik, 2024-03-27:
I was very, very exited of your work and unfortunately noticed that Aisler has discontinued producing the six-layer PCB's. Do you have any plans to try another supplier (Eurocircuits 6-layer boards are much more expensive though) or to try four-layer stack, would it just be a matter of scaling with the thickness?

KajWiik, 2024-03-27:
OK, I found your post in the Aisler community list. Very disappointing. It would be interesting to know any developments on this.

oberstet, 2024-03-28:
> It would be interesting to know any developments on this.

second that. I don't need it now (I only need <3GHz, and I need U.FL), but a proper high-end KiCad footprint (OSS) for a SMA edge connector - verified for a specific PCB manufacturer stack - would be pretty useful IMO!

fwiw, I have very little HW / PCB manufacturing experience. almost zero;) but I like JLCPCB, quick, professionel and cheap. obviously they have 6-layer, and lots of other variants (I used a 2-layer PTFE stack).

toammann, 2024-03-28:
Hello,

for reference: Find the link to the Aisler discontinuation [here:](https://community.aisler.net/t/6-layer-boards-discontinued/3574)

@KajWiik It is indeed very disappointing. The proposed design (as any other RF design) is highly sensitive to changes to the PCB design house. I was aware of that, but I did not expect a change so early after introduction of the stackup :(

[Multi-CB](https://www.multi-circuit-boards.eu/) may be the most promising alternative. However, I don't know if the "trick" with the castellated holes works also with multi-cb without additional cost. Anyways there are no short term plans to transfer the design to another stackup because the tunable filter for which these connectors were intended to is now also dead (for now).

@oberstet I expect JLCPCB to change their stackups even more frequently. I liked the close support of Aisler on the edge plating topic and I do not know about etching and via curacy of JLCPCB. I think the requirements on the PCB are too complicated. Anyways, I expect the communication to be more difficult with JLCPCB. Also, I do not want to order PCBs in China if other options exist. The PTFE Teflon boards can become interesting if more than 2 layers are available.

For hobbyist use, a design without edge plating may be more robust for the future.

Regards,
Tobias

oberstet, 2024-03-28:
Hi Tobias, obviously, you are an expert - and I am not;) I have a sample size of 1 from design to real PCB. And tbh, I actually was astonished I got that right in one try - including the cutouts/mouse bites and such for my test fixture boards. JLCPCB only had questions rgd placement of serial number (which I do want on every tile, to complement the CC level 4 tag I do place on the PCBs ... supply chain attestation and antenna HW pairing). The one "mistake" or slight problem is 100% my fault: I imagined the mouse bites to crack easily .. as they likely would with FR4 -- and they do in a way .. but the PTFE material is a bit like chewing gum .. so a cutter or scissors is better for clean break outs). Anyways, details. Cheers, /Tobias

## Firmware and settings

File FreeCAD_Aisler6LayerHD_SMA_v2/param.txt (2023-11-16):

pcb_x	20	Length of the pcb in the x-dimension
pcb_y	15	Length of the pcb in the y-dimension
pcb_th	1.4035	Total thickness of the pcb

port_length_x	6.5	Reserved length on the substrate for the openEMS port =B1 - (B7 + B12 + B61 + B64 + B66) - 5

slot_x	7	Length of the slot for the connector  in the x-dimension
slot_y	7.1	Length of the slot for the connector  in the y-dimension

edge_milling_tool_diam	1.8	Dimameter of the milling tool
edge_drill_diam	0.9	Diameter of the edge drill (tooling diamater)
edge_spacing_copper_x	0.2	Coppler clearance measured from the pcb edge in x-dimension
edge_spacing_via_x	0.3	Distance bewteen the board edge and a via coverpad
metal_remove_y	2.9	Copper removal at the slot in the y dimension	3.1
edge_plating_th	0.02	Thickness of the edge plating

conn_length_case	6.9	Length of the connector case
conn_length_thread	4	Length of the round connector part (with threead)
conn_sub_l_red	0.15	Substrate indentation
conn_inner_cond_pos_z	0.5	Z-Position of the inner conductor center point
conn_thread_d	5

conn_inner_cond_diam1	1.2	Diameter of the inner conductor (wide section)
conn_inner_cond_diam2	0.79	Diameter of the inner conductor (narrow section)
conn_inner_ext	2
conn_inner_sec1_x	3.6	Section 1 of the inner conducor - x-dimension
conn_inner_sec2_x	0.4
conn_inner_sec3_x	0.25
conn_inner_sec4_x	0.15
conn_inner_sec5_x	2.1
conn_inner_sec6_x	6.4
conn_inner_sec1_y	0.6	Section 1 of the inner conducor - y-dimension (only the half of the section is drawn due to rotation of the sketch to form the round geometry)
conn_inner_sec2_y	0.425
conn_inner_sec3_y	0.75
conn_inner_sec4_y	0	überbestimmt
conn_inner_sec5_y	0.6
conn_inner_sec6_y	0.395

conn_outer_cond_diam1	4	Diameter of the outer conductor 1 (wide section)
conn_outer_cond_diam2	2.5	Diameter of the outer conductor 1 (narrow section)
conn_outer_sec1_x	5.15
conn_outer_sec2_x	0.8
conn_outer_sec3_x	0.8
conn_outer_sec4_x	4
conn_outer_sec1_y	2
conn_outer_sec2_y	1.8
conn_outer_sec3_y	2
conn_outer_sec4_y	1.25

via_cp_d	0.6	Via coverpad diameter
via_d	0.3	Via diameter
via_pitch	0.6	Via pitch
via_trans_region_pos_x	7.6	Length of via transisition region (area with decreased gnd spacing)

solder_h	0.5	Height of solder joints
solder_excess_x	0.5	Excess of solder joints (extend in the x-dimension)
solder_length_y	1.5	Length of the solder joint in the y direction

l01_wg_trace_w	0.65	Width of the waveguide trace (microstrip)
l01_wg_trace_gndfree	3.1	Ground cutout around the microstrip on the top layer (total dimension including l01_wg_trace_w)
l01_pad_x	2	Connector solder pin pad x-dimension
l01_pad_y	1.1	Connector solder pin pad y-dimension
l01_pad2gnd_spacing_y	0.45	GND spacing in the via transition region	0.35
l01_compL_x	0.4	Length of the inductive compensation structure in the x-dimension	0.6
l01_compL_y	0.25	Length of the inductive compensation structure in the y-dimension	0.25
l01_compC_x	0.25	Length of the capacitive compensation structure in the x-dimension	0.4
l01_compC_y	1.2	Length of the capacitive compensation structure in the y-dimension	1.25
l01_gnd_trans_taper_len_x	0.5	Length of the taper (step in ground plane from the transition region to the microstrip region)

l03_gnd_ref_cutout_x	2	Cutout under the pad, x-dimension
l03_gnd_ref_cutout_y	2	Cutout under the pad, y-dimension

l01_th	0.04	Thickness of layer 01, copper
sub01_th	0.136	Thickness of substrate 01, prepreg
l02_th	0.035	Thickness of layer 02, copper
sub02_th	0.2	Thickness of substrate 02, core
l03_th	0.035	Thickness of layer 03, copper
sub03_th	0.5115	Thickness of substrate 03, prepreg
l04_th	0.035	Thickness of layer 04, copper
sub04_th	0.2	Thickness of substrate 04, core
l05_th	0.035	Thickness of layer 05, copper
sub05_th	0.136	Thickness of substrate 05, prepreg
l06_th	0.04	Thickness of layer 06, copper

l01_pos	-0.04	Referenced to top (most negatvie z value of the shape)
sub01_pos	-0.176
l02_pos	-0.211
sub02_pos	-0.411
l03_pos	-0.446
sub03_pos	-0.9575
l04_pos	-0.9925
sub04_pos	-1.1925
l05_pos	-1.2275
sub05_pos	-1.3635
l06_pos	-1.4035

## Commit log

2023-06-05 add FreeCAD model
    [Aisler6LayerHD_SMA_v2.FCStd, Aisler6LayerHD_SMA_v2.step, Aisler6LayerHD_SMA_v2_EdgePlating.dxf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]
2023-06-05 add KiCAD testboard
    [rosenberger_32K242-40ML5_testboard_v2.kicad_pcb, rosenberger_32K242-40ML5_testboard_v2.kicad_sch]
2023-06-05 rename folders, add KiCAD footprint
    [rosenberger_32K242-40ML5_testboard_v2.kicad_pcb, rosenberger_32K242-40ML5_testboard_v2.kicad_sch]
2023-06-05 fix typo
    [rosenberger_32K242-40ML5_testboard_v2.kicad_pcb, rosenberger_32K242-40ML5_testboard_v2.kicad_sch]
2023-06-05 add KiCAD footprint
2023-06-25 change Model directory name
    [Aisler6LayerHD_SMA_v2.FCStd, Aisler6LayerHD_SMA_v2.step, Aisler6LayerHD_SMA_v2_EdgePlating.dxf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]
2023-11-16 Change of outline milling tool to 1.8mm. Add Rosenberger 3D model from FreeCad
    [Aisler6LayerHD_SMA_v2.FCStd, Aisler6LayerHD_SMA_v2.step, Aisler6LayerHD_SMA_v2_L01.dxf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]
